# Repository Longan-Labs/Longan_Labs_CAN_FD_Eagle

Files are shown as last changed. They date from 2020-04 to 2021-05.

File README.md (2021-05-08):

(https://www.longan-labs.cc/can-bus/can-fd.html)

Eagle for [CAN FD Sheid](https://www.longan-labs.cc/1030012.html)

Base on MCP2517 and MCP2542

Click on [Longan-Labs.cc](https://www.longan-labs.cc/) to get the product you need.

Contact [support@longan-labs.cc](support@longan-labs.cc) if you need help.

Analytics (https://github.com/igrigorik/ga-beacon)

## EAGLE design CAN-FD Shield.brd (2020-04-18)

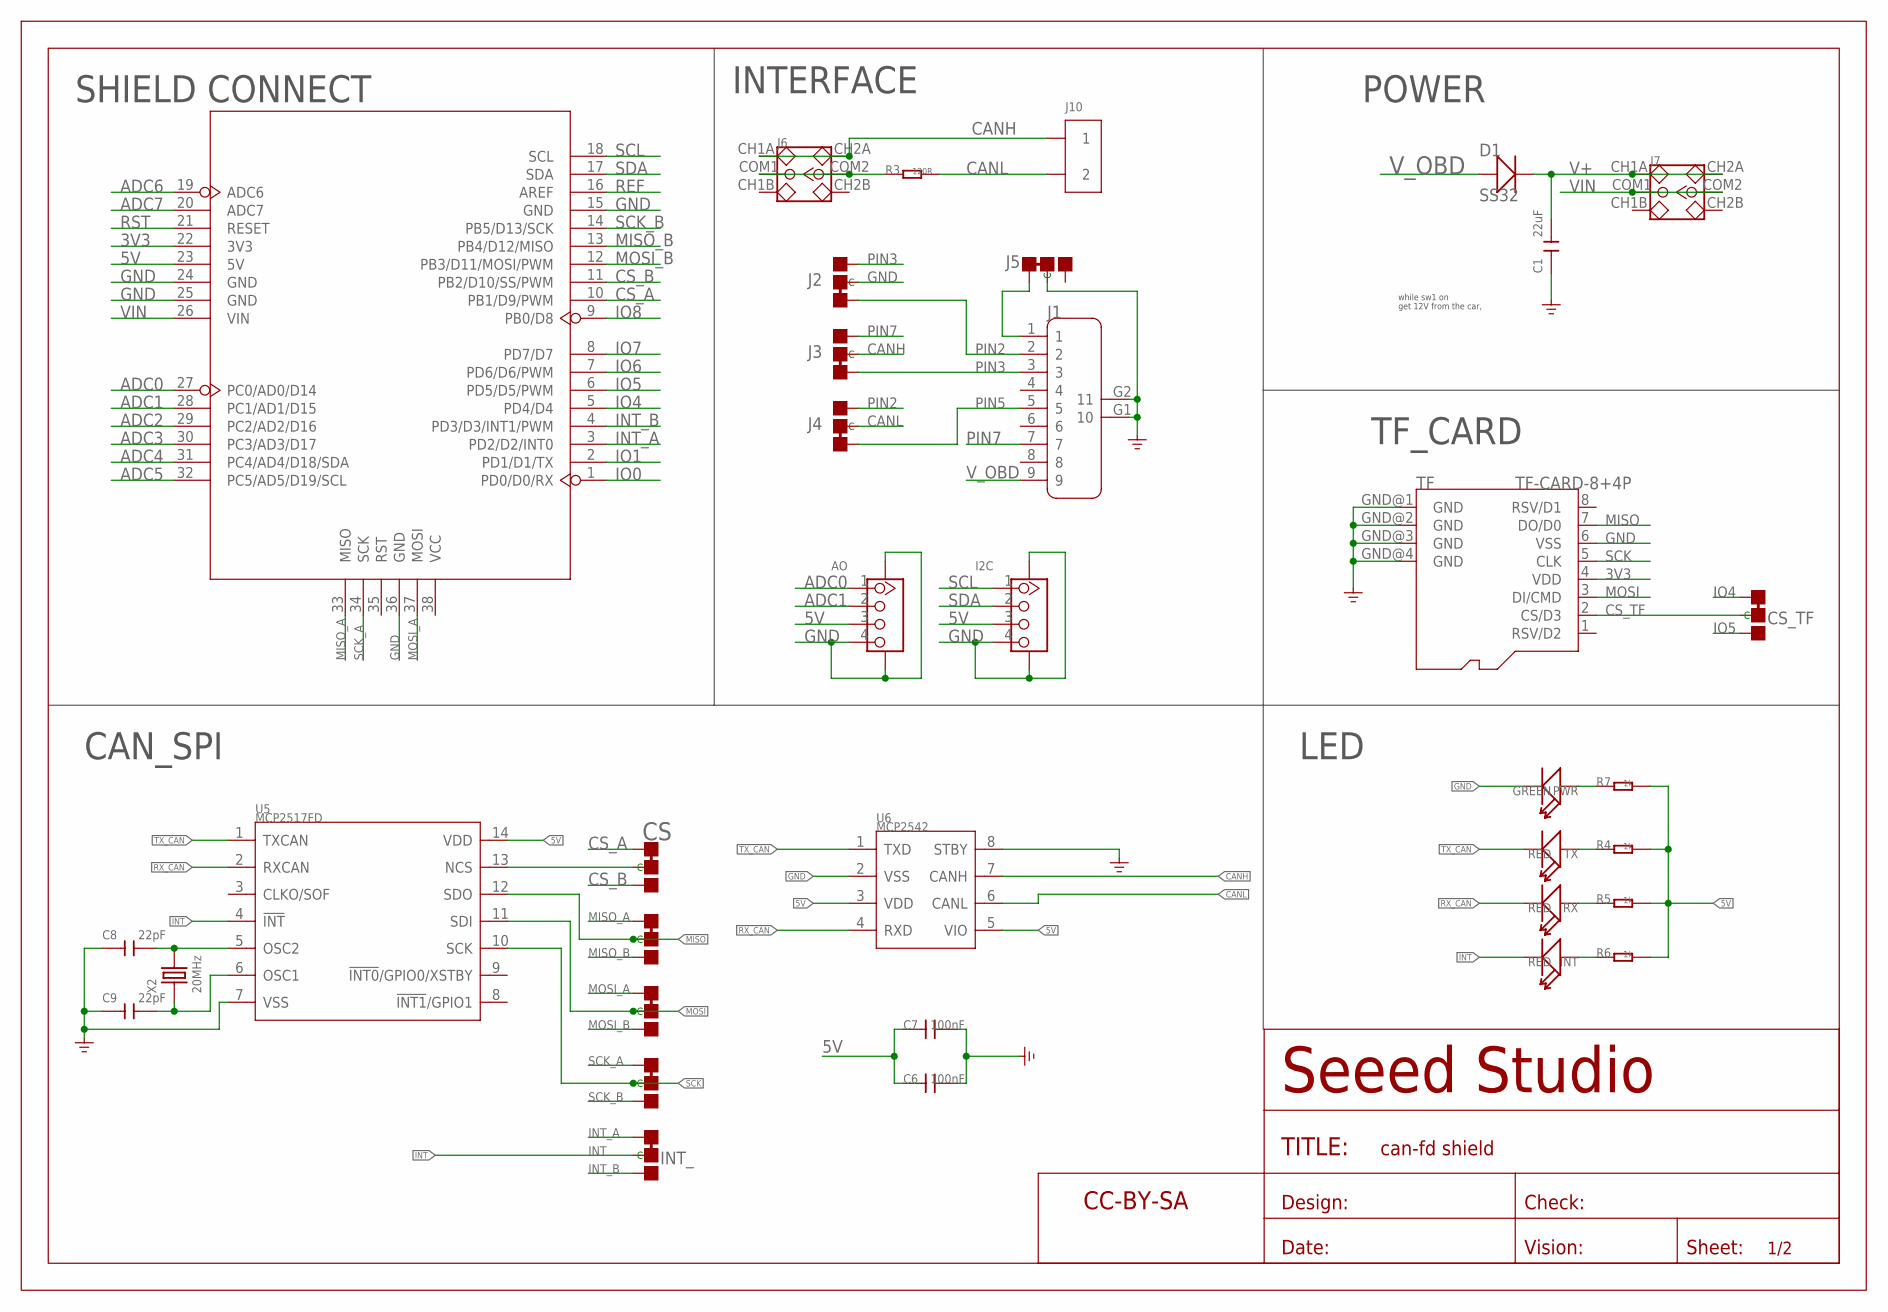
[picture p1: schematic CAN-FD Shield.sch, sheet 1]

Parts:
AO: GROVE-CONNECTOR-SMD'90D'; HW4-SMD-2.0-90D
C1: 22uF; C1206
C6, C7: 100nF; 0603
C8, C9: 22pF; C0603
CS: JUMPER-3P-SHORT; 3P-SMD-SHORT
CS_TF: JUMPER-3P-SHORT; 3P-SMD-SHORT
D1: SS32; D2010
I2C: GROVE-CONNECTOR-SMD'90D'; HW4-SMD-2.0-90D
INT: RED; LED-0603
INT_: JUMPER-3P-SHORT; 3P-SMD-SHORT
J1: DB9'MEAL'; DB9-MEAL
J2, J3, J4, J5: JUMPER-3P-SHORT; 3P-SMD-SHORT
J6, J7: SWITCH-2CH-6P; 6P-2CH-2.54-7.6X3.0
J10: SCREW-TERMINAL-2P'5.08'; H2-5.0-10.5X8.0MM
MISO: JUMPER-3P-SHORT; 3P-SMD-SHORT
MOSI: JUMPER-3P-SHORT; 3P-SMD-SHORT
PWR: GREEN; LED-0603
R3: 120R; 0603
R4, R5, R6, R7: 1k; 0603
RX: RED; LED-0603
SCK: JUMPER-3P-SHORT; 3P-SMD-SHORT
TF: TF-CARD-8+4P; TF-8+4P-1.1-13.5X15MM
TX: RED; LED-0603
U4: ARDUINO-38P'WITH/-SILK'; ARDUINO-38P-WITH/-SILK-500519002
U5: MCP2517FD; SOIC14-1.27-8.6X3.9MM
U6: MCP2542; SOIC8-1.27-5X4MM
U$5: SEEEDSTUDIO-OPEN-SCH-FRAME; SEEEDSTUDIO-PCB-FRAME
X2: 20MHz; HC49US

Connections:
3V3: TF.4 (VDD), U4.22 (3V3)
5V: AO.3, C6.1, C7.1, I2C.3, R4.2, R5.2, R6.2, R7.2, U4.23 (5V), U5.14 (VDD), U6.3 (VDD), U6.5 (VIO)
ADC0: AO.1, U4.27 (PC0/AD0/D14)
ADC1: AO.2, U4.28 (PC1/AD1/D15)
ADC2: U4.29 (PC2/AD2/D16)
ADC3: U4.30 (PC3/AD3/D17)
ADC4: U4.31 (PC4/AD4/D18/SDA)
ADC5: U4.32 (PC5/AD5/D19/SCL)
ADC6: U4.19 (ADC6)
ADC7: U4.20 (ADC7)
CANH: J3.MM (C), J6.CH1A, J6.CH2A, J10.1, U6.7 (CANH)
CANL: J4.MM (C), J10.2, R3.2, U6.6 (CANL)
CS_A: CS.11 (L), U4.10 (PB1/D9/PWM)
CS_B: CS.00 (R), U4.11 (PB2/D10/SS/PWM)
CS_TF: CS_TF.MM (C), TF.2 (CS/D3)
GND: AO.4, AO.SS1, AO.SS2, C1.1, C6.2, C7.2, C8.1, C9.1, I2C.4, I2C.SS1, I2C.SS2, J1.G1 (10), J1.G2 (11), J2.MM (C), J5.MM (C), PWR.-, TF.6 (VSS), TF.GND@1 (GND), TF.GND@2 (GND), TF.GND@3 (GND), TF.GND@4 (GND), U4.15 (GND), U4.24 (GND), U4.25 (GND), U4.36 (GND), U5.7 (VSS), U6.2 (VSS), U6.8 (STBY)
INT: INT.-, INT_.MM (C), U5.4 (!INT)
INT_A: INT_.11 (L), U4.3 (PD2/D2/INT0)
INT_B: INT_.00 (R), U4.4 (PD3/D3/INT1/PWM)
IO0: U4.1 (PD0/D0/RX)
IO1: U4.2 (PD1/D1/TX)
IO4: CS_TF.11 (L), U4.5 (PD4/D4)
IO5: CS_TF.00 (R), U4.6 (PD5/D5/PWM)
IO6: U4.7 (PD6/D6/PWM)
IO7: U4.8 (PD7/D7)
IO8: U4.9 (PB0/D8)
MISO: MISO.MM (C), TF.7 (DO/D0), U5.12 (SDO)
MISO_A: MISO.11 (L), U4.33 (MISO)
MISO_B: MISO.00 (R), U4.13 (PB4/D12/MISO)
MOSI: MOSI.MM (C), TF.3 (DI/CMD), U5.11 (SDI)
MOSI_A: MOSI.11 (L), U4.37 (MOSI)
MOSI_B: MOSI.00 (R), U4.12 (PB3/D11/MOSI/PWM)
unnamed: PWR.+, R7.1
unnamed: R4.1, TX.+
unnamed: J6.COM1, J6.COM2, R3.1
unnamed: J1.1, J5.11 (L)
unnamed: C8.2, U5.5 (OSC2), X2.2
unnamed: CS.MM (C), U5.13 (NCS)
unnamed: R5.1, RX.+
unnamed: C9.2, U5.6 (OSC1), X2.1
unnamed: INT.+, R6.1
PIN2: J1.2, J2.11 (L), J4.00 (R)
PIN3: J1.3, J2.00 (R), J3.11 (L)
PIN5: J1.5, J4.11 (L)
PIN7: J1.7, J3.00 (R)
REF: U4.16 (AREF)
RST: U4.21 (RESET)
RX_CAN: RX.-, U5.2 (RXCAN), U6.4 (RXD)
SCK: SCK.MM (C), TF.5 (CLK), U5.10 (SCK)
SCK_A: SCK.11 (L), U4.34 (SCK)
SCK_B: SCK.00 (R), U4.14 (PB5/D13/SCK)
SCL: I2C.1, U4.18 (SCL)
SDA: I2C.2, U4.17 (SDA)
TX_CAN: TX.-, U5.1 (TXCAN), U6.1 (TXD)
V+: C1.2, D1.-, J7.CH1A, J7.CH2A
VIN: J7.COM1, J7.COM2, U4.26 (VIN)
V_OBD: D1.+, J1.9

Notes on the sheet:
CAN_SPI
SHIELD CONNECT
INTERFACE
POWER
get 12V from the car,
while sw1 on
TF_CARD
LED

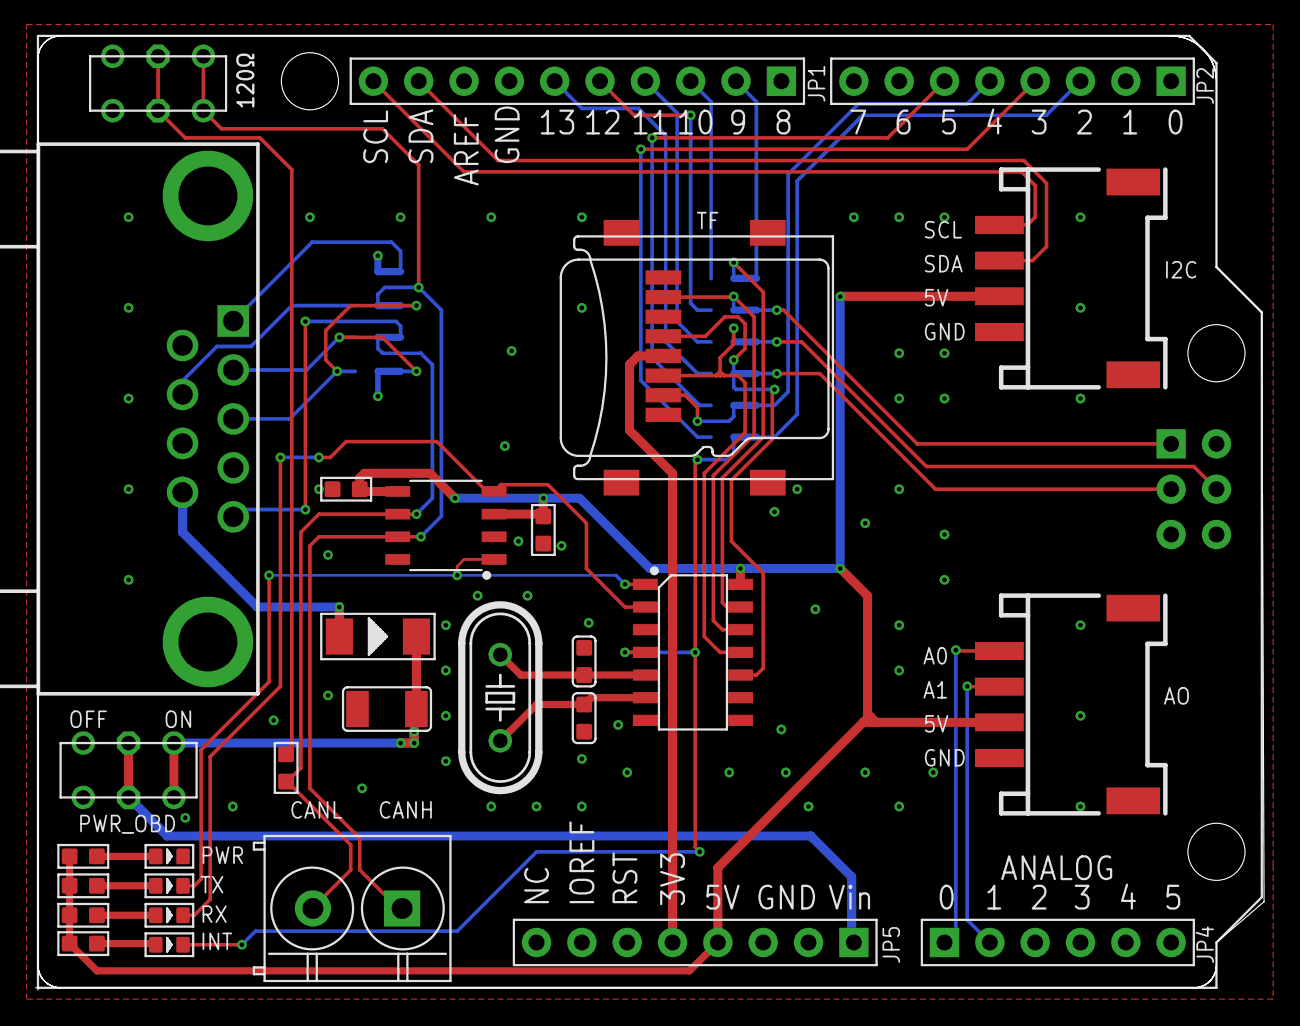
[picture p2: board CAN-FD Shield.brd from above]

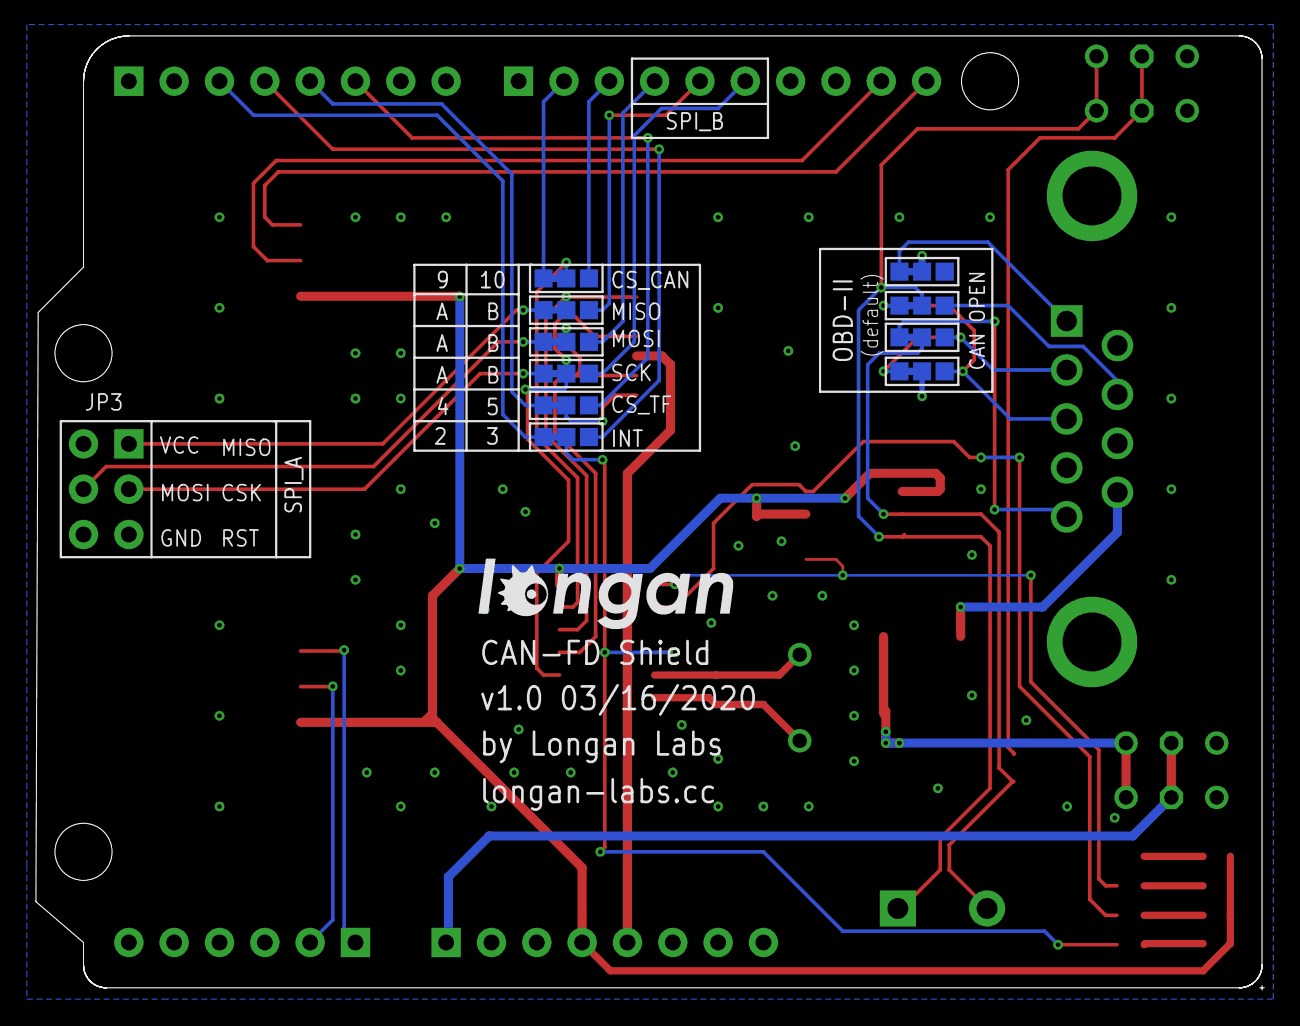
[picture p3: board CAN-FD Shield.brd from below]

Board: 2 copper layers, 68.7 x 53.3 mm, 38 parts (11 on the bottom side), 44 nets.

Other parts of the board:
U$1: LONGAN-SILK-SMALLER

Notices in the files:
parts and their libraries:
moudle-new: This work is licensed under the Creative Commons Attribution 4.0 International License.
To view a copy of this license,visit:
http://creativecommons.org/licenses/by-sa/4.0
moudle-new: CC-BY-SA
